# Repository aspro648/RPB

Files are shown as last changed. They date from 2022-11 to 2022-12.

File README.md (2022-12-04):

Rapid Prototyping Board
-------------------------------
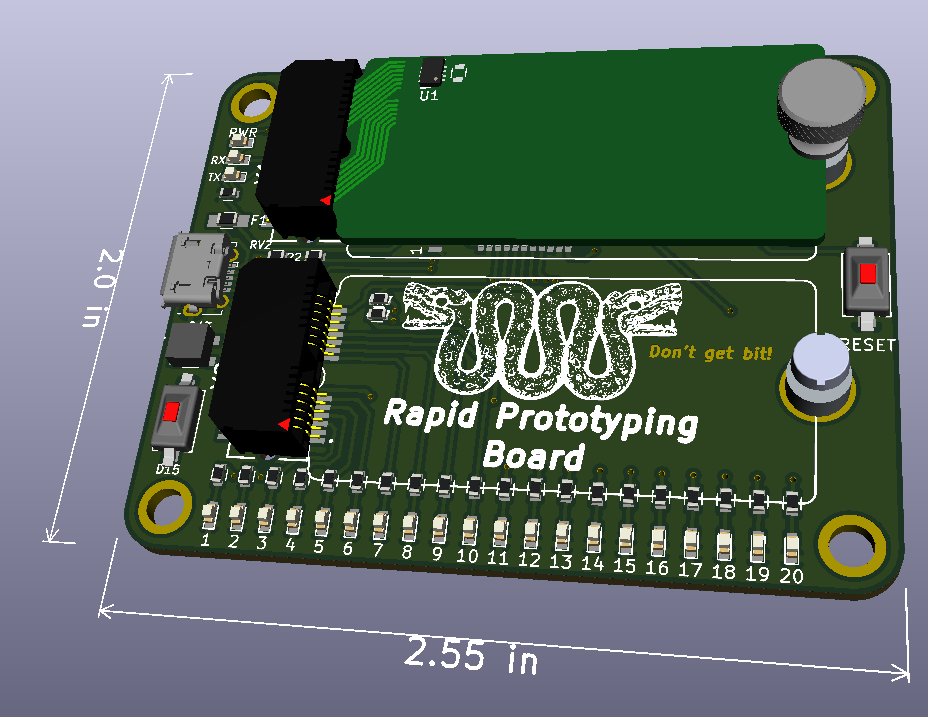
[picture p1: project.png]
 

What is it?
-----------

- Basically a 32U4 based Arduino with two card-edge slots instead of a shield layout.

Why?
----

- It started out as a 20-pin harness tester (Use Case 1), but morphed into a more generic prototyping system.
- Allows you to quickly prototype systems out on inexpensive small PCBs

Features:
---------

- USB programable Atmega 32U4.
- 20 i/o lines on card 1 position.
- Power, i2c, SPI on both card positions.
- Ability to check what card is plugged in each bay.

License
----------------
[Attribution-ShareAlike 3.0 United States (CC BY-SA 3.0 US)](https://creativecommons.org/licenses/by-sa/3.0/us/)

You are free to:

- Share — copy and redistribute the material in any medium or format
- Adapt — remix, transform, and build upon the material

Under the following terms:

- Attribution — You must give appropriate credit, provide a link to the license, and indicate if changes were made. You may do so in any reasonable manner, but not in any way that suggests the licensor endorses you or your use.
- ShareAlike — If you remix, transform, or build upon the material, you must distribute your contributions under the same license as the original.

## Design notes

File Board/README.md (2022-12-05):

Rapid Prototyping Board
-----------------------
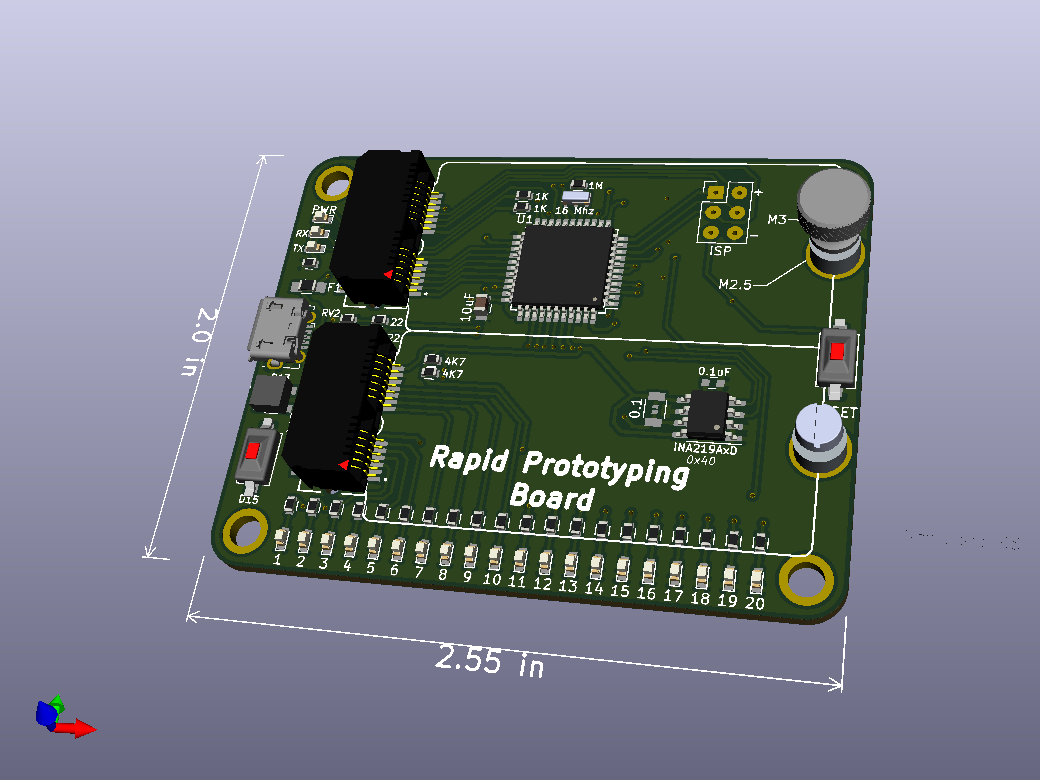
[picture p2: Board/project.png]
 

Bill Of Materials
----------------
  
- 1 ea., Perfect Purple PCB from OSH Park, https://oshpark.com/shared_projects/RGBCuiso
- 1 ea., U1 ATMEGA32U4-AU, IC MCU 8BIT 32KB FLASH 44TQFP, https://www.digikey.com/short/jb25pc
- 1 ea., U2 IC CURRENT MONITOR 1% 8SOIC, TI INA219AIDR, https://www.digikey.com/short/z32drn7n
- 1 ea., Y1 CER RES 16.0000MHZ 15PF SMD, Murata CSTNE16M0V530000R0, https://www.digikey.com/short/8nzcmjh3
- 2 ea., C1 CAP CER 10UF 10V X5R 0805, Kemet C0805C106K8PAC7800, https://www.digikey.com/short/32v75tfv
- 1 ea., C2 CAP CER 0.1uF 0603, https://www.digikey.com/short/h3jddqhm 
- 23 ea., D1-D23 SMD LED GREEN 0603, Lite-On LTST-C191KGKT, https://www.digikey.com/short/ptwhtwz2
- 1 ea., F1	PTC RESET FUSE 6V 500MA 0805 Eaton PTS08056V050, https://www.digikey.com/short/4182mdqq
- 2 ea., RV1, RV2 VARISTOR 10.8V 30A 0603, KYOCERA VCUG060050L1DP, https://www.digikey.com/short/0479hw0m
- 23 ea., R1-R23 Resistor 1K OHM SMD 0603, Stackpole RNCP0603FTD1K00, https://www.digikey.com/short/704h9hfn
- 2 ea., R24, R25 Resistor 22 OHM SMD 0603, Yageo RC0603JR-0722RL, https://www.digikey.com/short/93jrm3t2
- 1 ea., R26 Resistor 1M OHM SMD 0603 Yageo RC0603JR-071ML, https://www.digikey.com/short/z0jnrwbq
- 2 ea., R27, R28 Resistor 4K7 OHM SMD 0603, https://www.digikey.com/short/t89ptvpw
- 1 ea., R29 RES 0.1 OHM 1% 1W 1206, VSRP1206S1-R100F, https://www.digikey.com/short/dzw3vt1h
- 2 ea., SW1 SWITCH TACTILE SPST-NO 0.05A 12V, Wurth 434121025816, https://www.digikey.com/short/qbm0p0c9
- 1 ea., J1 CONN RCPT MICRO USB R/A SMD, Molex 1050170001, https://www.digikey.com/short/jb2205
- 2 ea., X1, X2 CONN EDGE DUAL FMALE 20POS, Samtek MEC8-113-02-L-D-RA1, https://www.digikey.com/short/50wdhmp0
- 2 ea., ROUND STANDOFF M2.5 STEEL 2.7MM, Wurth 9774027151R, https://www.digikey.com/short/47zwt3m4
- 1 ea., LED1 3535 RGB LED,  IN-PI33TBTPRPGPB https://www.digikey.com/short/qf2t8bqj
- 4 ea., BUMPER CYLINDRICAL 0.25" DIA CLR, https://www.digikey.com/short/23cbvbh5
- 2 ea., M2.5 thumbscrew https://www.mcmaster.com/99607A263/ or
		 https://www.amazon.com/CNBTR-M2-5x6mm-Knurled-Threaded-Fastener/dp/B07ZJFGGTD

Card:
- 1 ea., RPB Card 2.54mm Pitch, https://oshpark.com/shared_projects/RnMvuNFo
- 1 ea., RES 10K OHM 5% 1/10W 0603, https://www.digikey.com/short/h4w9vtd1
- 1 ea., IC EEPROM 32KBIT I2C, Microchip 24LC32AT-I/MC, https://www.digikey.com/short/r3f225vm
- 1 ea., I2C Display Module 0.91 Inch I2C, https://www.amazon.com/Pieces-Display-Module-SSD1306-Screen/dp/B08N6N8L5Q

Stencil & Jig:
- https://www.oshstencils.com/#invoice/5585b4301f5fdfe7690882e8abfac3aeba5187

License
----------------
[Attribution-ShareAlike 3.0 United States (CC BY-SA 3.0 US)](https://creativecommons.org/licenses/by-sa/3.0/us/)

You are free to:

- Share — copy and redistribute the material in any medium or format
- Adapt — remix, transform, and build upon the material

Under the following terms:

- Attribution — You must give appropriate credit, provide a link to the license, and indicate if changes were made. You may do so in any reasonable manner, but not in any way that suggests the licensor endorses you or your use.
- ShareAlike — If you remix, transform, or build upon the material, you must distribute your contributions under the same license as the original.

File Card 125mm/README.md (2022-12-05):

Rapid Prototyping Card - 1.25mm Pitch
-------------------------------------

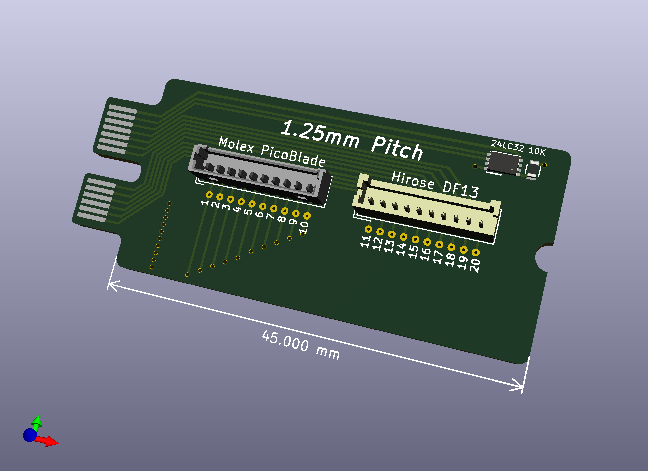
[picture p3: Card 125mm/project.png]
 

Bill Of Materials
----------------
  
- PCB from KiCad project.kicad_pcb file  
- 1 ea., RES 10K OHM 5% 1/10W 0603, https://www.digikey.com/short/h4w9vtd1
- 1 ea., IC EEPROM 32KBIT I2C, Microchip 24LC32AT-I/MC, https://www.digikey.com/short/r3f225vm
- 1 ea., CONN HEADER VERT 10POS 1.25MM, Molex 0530471010, https://www.digikey.com/short/jfwfhm5n
- 1 ea., CONN HEADER VERT 10POS 1.25MM, Hirose DF13-10P-1.25DSA, https://www.digikey.com/short/f5pm7mt2

License
----------------
[Attribution-ShareAlike 3.0 United States (CC BY-SA 3.0 US)](https://creativecommons.org/licenses/by-sa/3.0/us/)

You are free to:

- Share — copy and redistribute the material in any medium or format
- Adapt — remix, transform, and build upon the material

Under the following terms:

- Attribution — You must give appropriate credit, provide a link to the license, and indicate if changes were made. You may do so in any reasonable manner, but not in any way that suggests the licensor endorses you or your use.
- ShareAlike — If you remix, transform, or build upon the material, you must distribute your contributions under the same license as the original.

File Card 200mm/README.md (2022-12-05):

Rapid Prototyping Card - 2.00mm Pitch
-------------------------------------

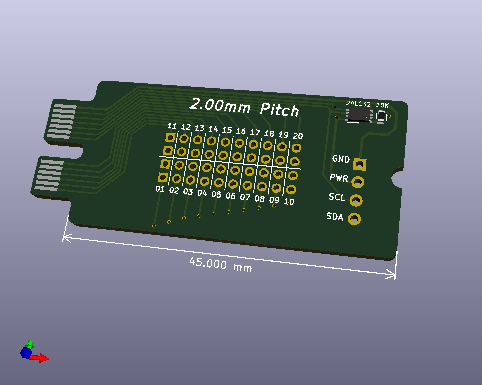
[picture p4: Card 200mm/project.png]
 

Bill Of Materials
----------------
  
- PCB from KiCad project.kicad_pcb file  
- 1 ea., RES 10K OHM 5% 1/10W 0603, https://www.digikey.com/short/h4w9vtd1
- 1 ea., IC EEPROM 32KBIT I2C, Microchip 24LC32AT-I/MC, https://www.digikey.com/short/r3f225vm

License
----------------
[Attribution-ShareAlike 3.0 United States (CC BY-SA 3.0 US)](https://creativecommons.org/licenses/by-sa/3.0/us/)

You are free to:

- Share — copy and redistribute the material in any medium or format
- Adapt — remix, transform, and build upon the material

Under the following terms:

- Attribution — You must give appropriate credit, provide a link to the license, and indicate if changes were made. You may do so in any reasonable manner, but not in any way that suggests the licensor endorses you or your use.
- ShareAlike — If you remix, transform, or build upon the material, you must distribute your contributions under the same license as the original.

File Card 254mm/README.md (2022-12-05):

Rapid Prototyping Card - 2.54mm Pitch
-------------------------------------

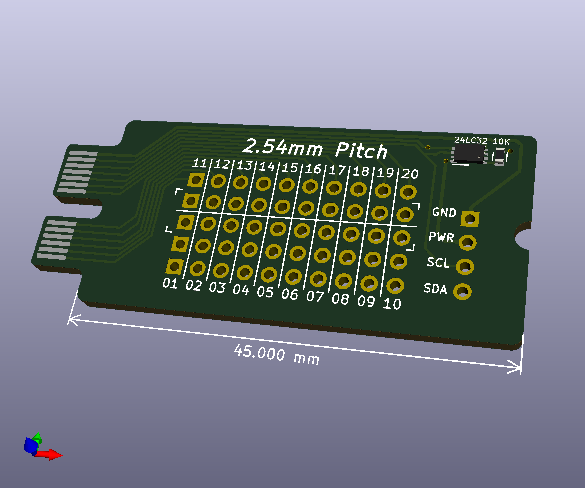
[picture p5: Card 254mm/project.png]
 

Bill Of Materials
----------------
  
- PCB from KiCad project.kicad_pcb file  
- 1 ea., RES 10K OHM 5% 1/10W 0603, https://www.digikey.com/short/h4w9vtd1
- 1 ea., IC EEPROM 32KBIT I2C, Microchip 24LC32AT-I/MC, https://www.digikey.com/short/r3f225vm

License
----------------
[Attribution-ShareAlike 3.0 United States (CC BY-SA 3.0 US)](https://creativecommons.org/licenses/by-sa/3.0/us/)

You are free to:

- Share — copy and redistribute the material in any medium or format
- Adapt — remix, transform, and build upon the material

Under the following terms:

- Attribution — You must give appropriate credit, provide a link to the license, and indicate if changes were made. You may do so in any reasonable manner, but not in any way that suggests the licensor endorses you or your use.
- ShareAlike — If you remix, transform, or build upon the material, you must distribute your contributions under the same license as the original.

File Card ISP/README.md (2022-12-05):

Rapid Prototyping Card - ArduinoISP
---------------------------------------
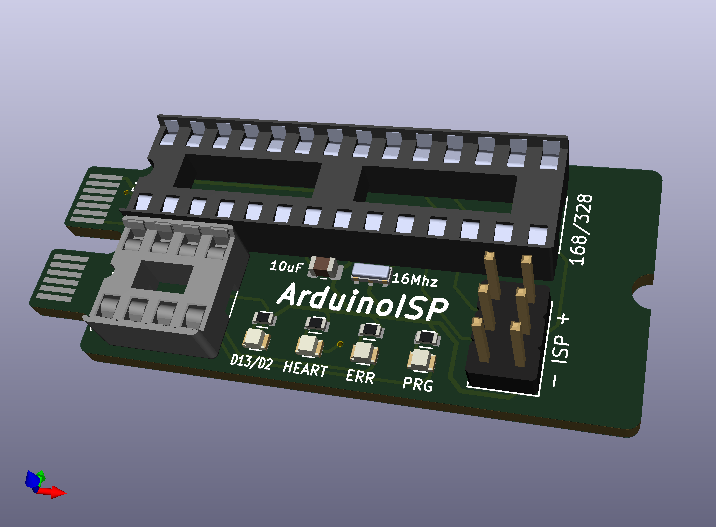
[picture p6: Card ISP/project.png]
 

What is it?
-----------

- Use RPB as an ISP programmer. 
- Sockets for Atmega8/168/328 & Attiny25/24/85.
- ISP jumper for on-board programming.
- D13 (Atmega) and D2 (Attiny) LED for troubleshooting.
- Fused to prevent reversed Attiny meltdown!

Bill Of Materials
----------------
  
- 1 ea., Perfect Purple PCB from OSH Park, https://oshpark.com/shared_projects/yUt0KZ6C
- 2 ea., C1 CAP CER 10UF 10V X5R 0805, Kemet C0805C106K8PAC7800, https://www.digikey.com/short/32v75tfv
- 2 ea., SMD LED GREEN 0603, Lite-On LTST-C191KGKT, https://www.digikey.com/short/ptwhtwz2
- 1 ea., SMD LED RED 0603, Lite-On LTST-C191KRKT, https://www.digikey.com/short/1p9dvv1t
- 1 ea., SMD LED YELLOW 0603, Lite-On LTST-C191KSKT, https://www.digikey.com/short/d20z9t1z
- 1 ea., PTC RESET FUSE 20V 54MA 0805, Murata PRG21AR420MB1RA, https://www.digikey.com/short/2nmhrbvf
- 4 ea., Resistor 1K OHM SMD 0603, Stackpole RNCP0603FTD1K00, https://www.digikey.com/short/704h9hfn
- 1 ea., CONN IC DIP SOCKET 28POS TIN, On Shore ED281DT, https://www.digikey.com/short/d8nq4rd3
- 1 ea., CONN IC DIP SOCKET 8POS, On Shore ED08DT, https://www.digikey.com/short/3tnrjzh5
- 1 ea., 6-PIN SOCKET/SOCKET IDC CABLE, Adafruit 371, https://www.digikey.com/short/b992qfbd
- 1 ea., CONN HEADER VERT 6POS 2.54MM, Amphenol 77313-118-06LF, https://www.digikey.com/short/r2d1pw4f

License
----------------
[Attribution-ShareAlike 3.0 United States (CC BY-SA 3.0 US)](https://creativecommons.org/licenses/by-sa/3.0/us/)

You are free to:

- Share — copy and redistribute the material in any medium or format
- Adapt — remix, transform, and build upon the material

Under the following terms:

- Attribution — You must give appropriate credit, provide a link to the license, and indicate if changes were made. You may do so in any reasonable manner, but not in any way that suggests the licensor endorses you or your use.
- ShareAlike — If you remix, transform, or build upon the material, you must distribute your contributions under the same license as the original.

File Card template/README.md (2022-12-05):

Rapid Prototyping Card - Template
---------------------------------
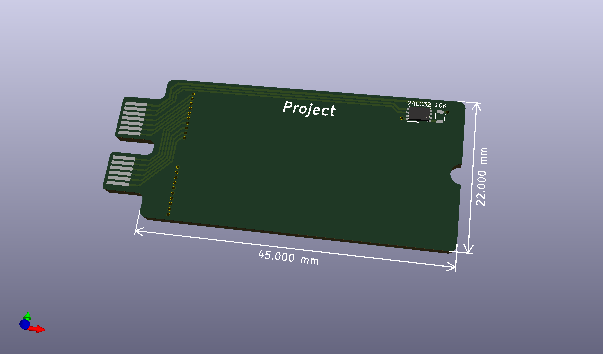
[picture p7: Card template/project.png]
 

Bill Of Materials
----------------

- PCB from KiCad project.kicad_pcb file  
- 1 ea., RES 10K OHM 5% 1/10W 0603, https://www.digikey.com/short/h4w9vtd1
- 1 ea., IC EEPROM 32KBIT I2C, Microchip 24LC32AT-I/MC, https://www.digikey.com/short/r3f225vm

License
----------------
[Attribution-ShareAlike 3.0 United States (CC BY-SA 3.0 US)](https://creativecommons.org/licenses/by-sa/3.0/us/)

You are free to:

- Share — copy and redistribute the material in any medium or format
- Adapt — remix, transform, and build upon the material

Under the following terms:

- Attribution — You must give appropriate credit, provide a link to the license, and indicate if changes were made. You may do so in any reasonable manner, but not in any way that suggests the licensor endorses you or your use.
- ShareAlike — If you remix, transform, or build upon the material, you must distribute your contributions under the same license as the original.

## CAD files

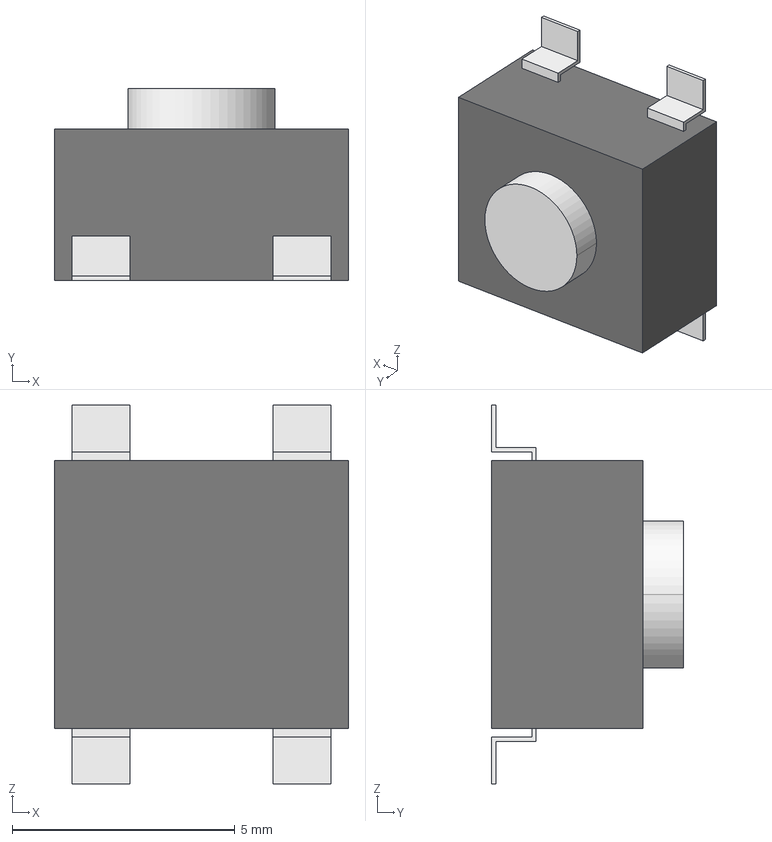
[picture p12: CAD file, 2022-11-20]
Board/3D/Button_b3s-1002p.stp
6.60 x 4.30 x 8.50 mm

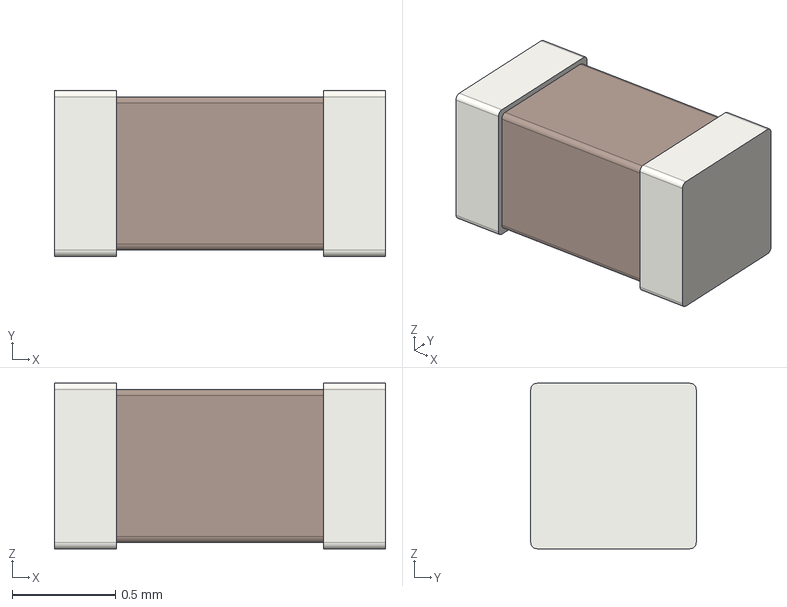
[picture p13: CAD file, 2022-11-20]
Board/3D/C_0603_1608Metric.step
1.60 x 0.8 x 0.8 mm

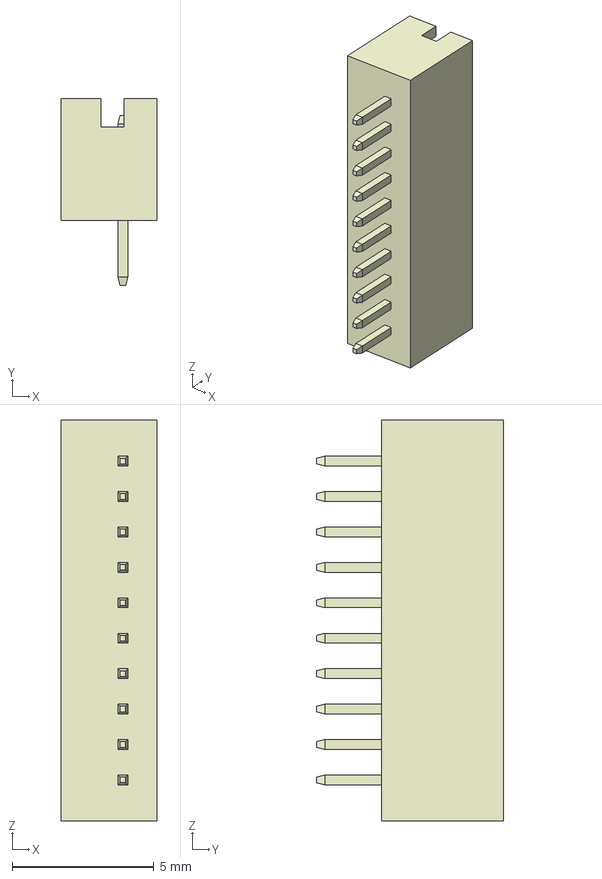
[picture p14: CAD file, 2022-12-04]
Card 125mm/3D/DF13-10P-1.25DSA.stp
3.40 x 6.60 x 14.1 mm

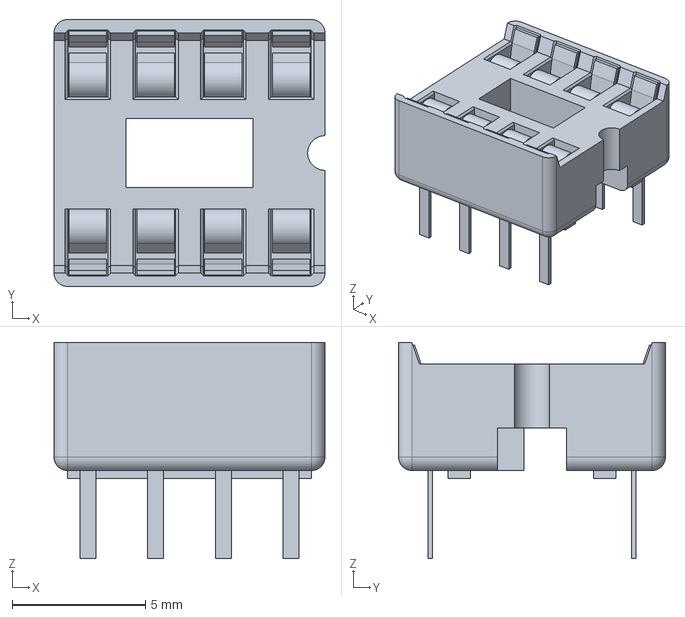
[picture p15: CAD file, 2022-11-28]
Card ISP/3D/c-1-2199298-2-a-3d.stp
10.2 x 10.0 x 8.10 mm

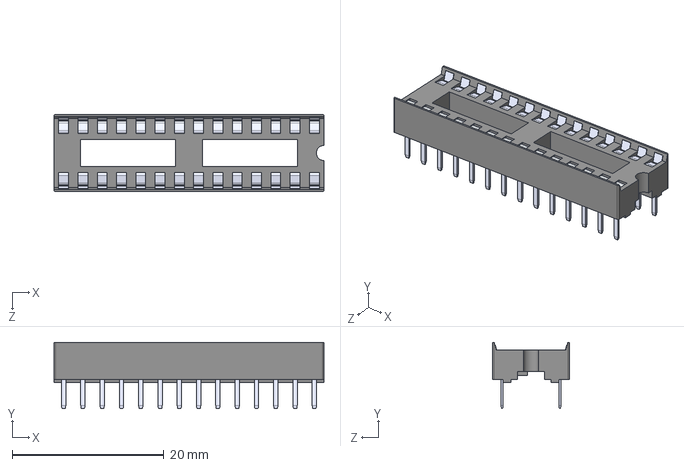
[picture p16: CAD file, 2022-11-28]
Card ISP/3D/ED281DT--3DModel-STEP-56544.STEP
35.6 x 8.70 x 10.2 mm

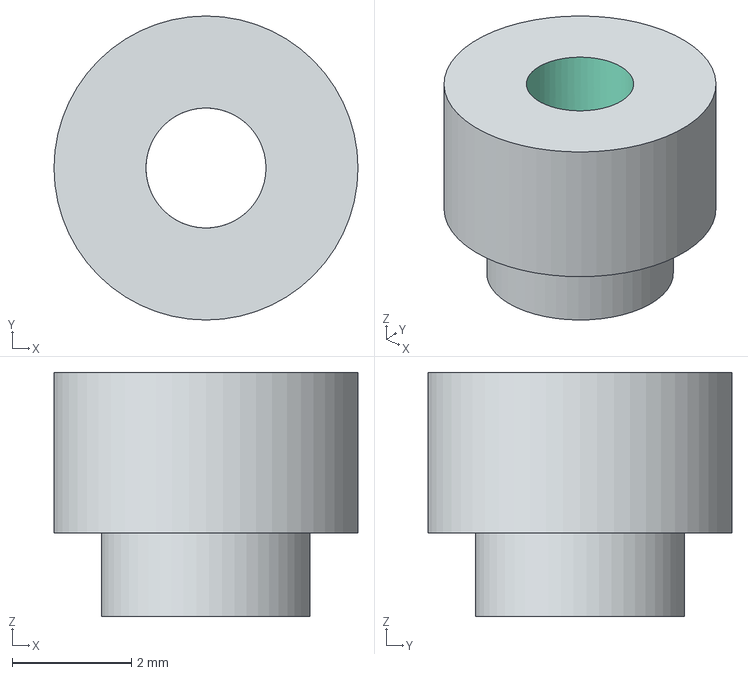
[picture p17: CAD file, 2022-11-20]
Board/3D/standoff9774027151R (rev1).stp
5.10 x 5.10 x 4.10 mm

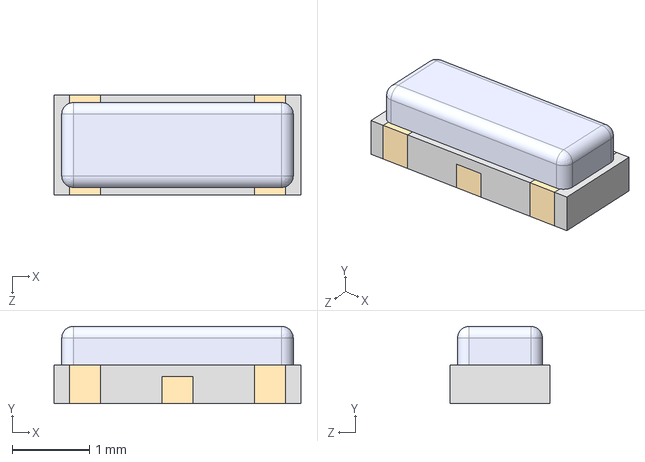
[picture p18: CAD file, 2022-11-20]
Card ISP/3D/resontator_CSTNE16M0V530000R0.STEP
3.20 x 1.00 x 1.30 mm

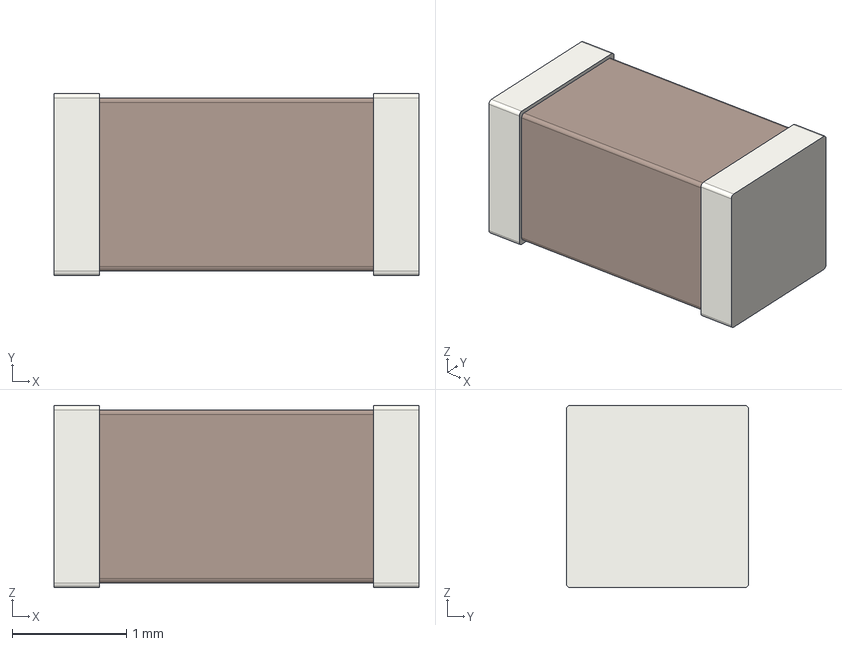
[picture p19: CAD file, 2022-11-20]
Board/3D/C_1206_3216Metric.step
3.20 x 1.60 x 1.60 mm

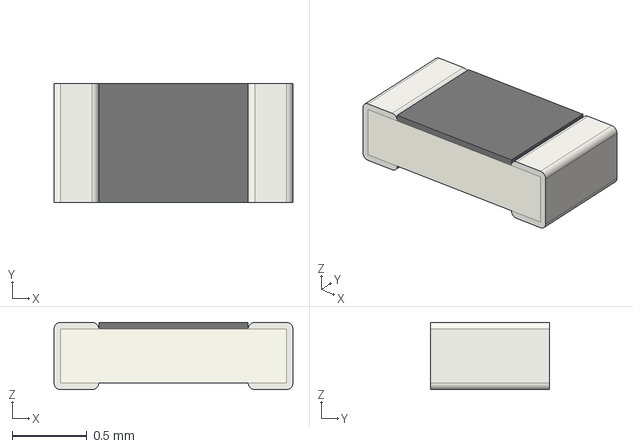
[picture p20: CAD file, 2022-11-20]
Board/3D/R_0603_1608Metric.step
1.60 x 0.8 x 0.45 mm

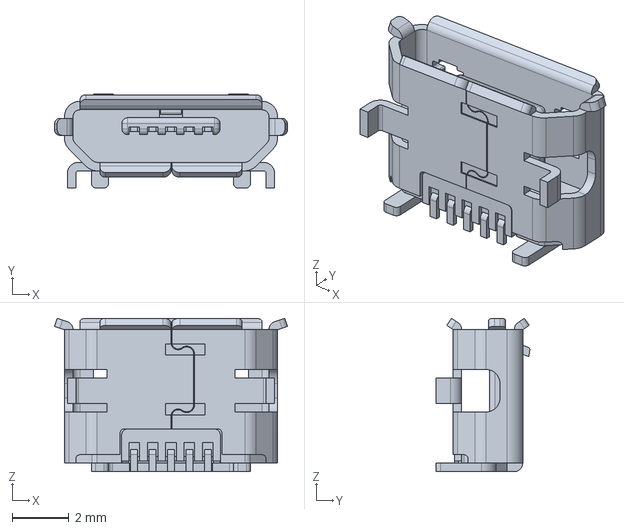
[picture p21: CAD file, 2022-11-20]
Board/3D/USB_micro_105017-0001.stp
8.20 x 3.30 x 5.40 mm

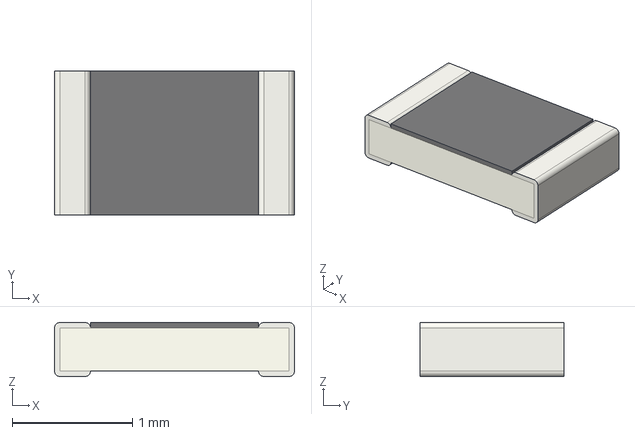
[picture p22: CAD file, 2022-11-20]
Board/3D/R_0805_2012Metric.step
2.00 x 1.20 x 0.45 mm

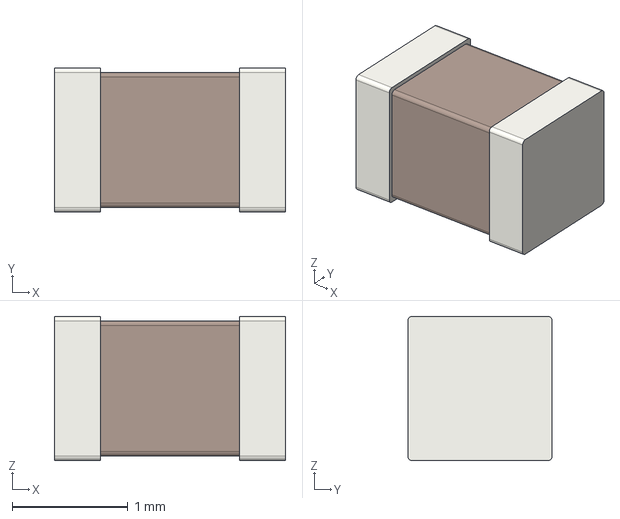
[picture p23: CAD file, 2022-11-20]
Board/3D/C_0805_2012Metric.step
2.00 x 1.25 x 1.25 mm

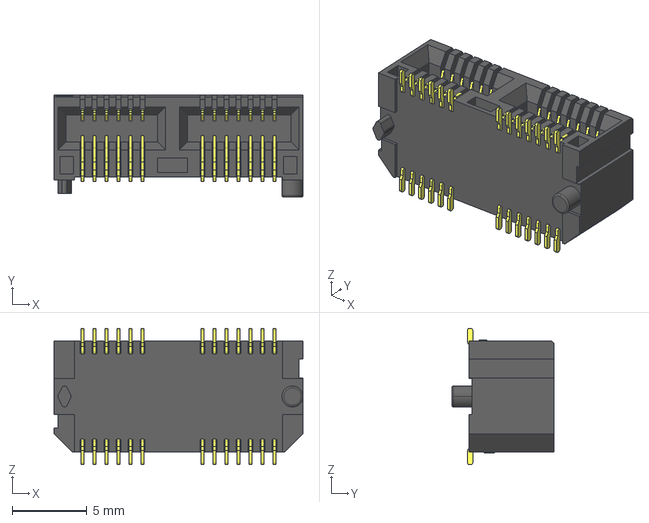
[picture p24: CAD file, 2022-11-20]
Board/3D/mec8-113-02-l-d-ra1.stp
16.6 x 6.83 x 9.10 mm

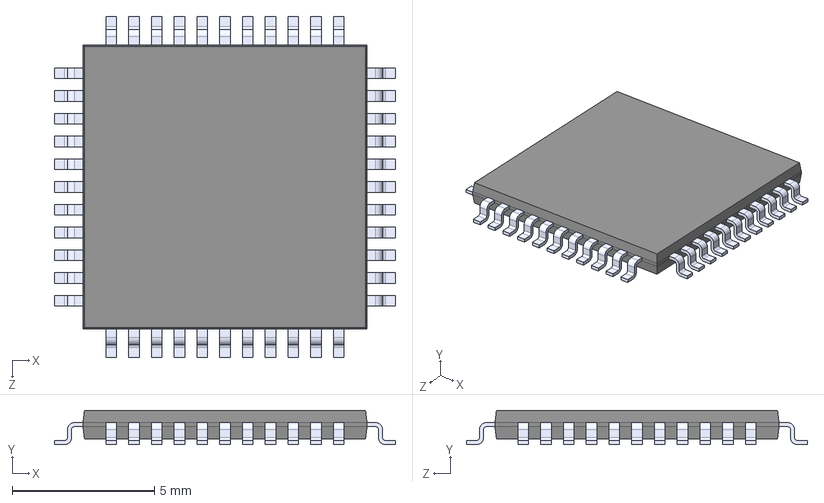
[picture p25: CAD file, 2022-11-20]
Board/3D/ATMEGA32U4-AUR--3DModel-STEP-56544.STEP
12.0 x 1.20 x 12.0 mm

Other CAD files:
Board/3D/1655.step
Card 125mm/3D/530471010.stp
Card ISP/3D/61200621621_Download_STP_61200621621_rev1.stp
Board/3D/M2_5X6MM.step

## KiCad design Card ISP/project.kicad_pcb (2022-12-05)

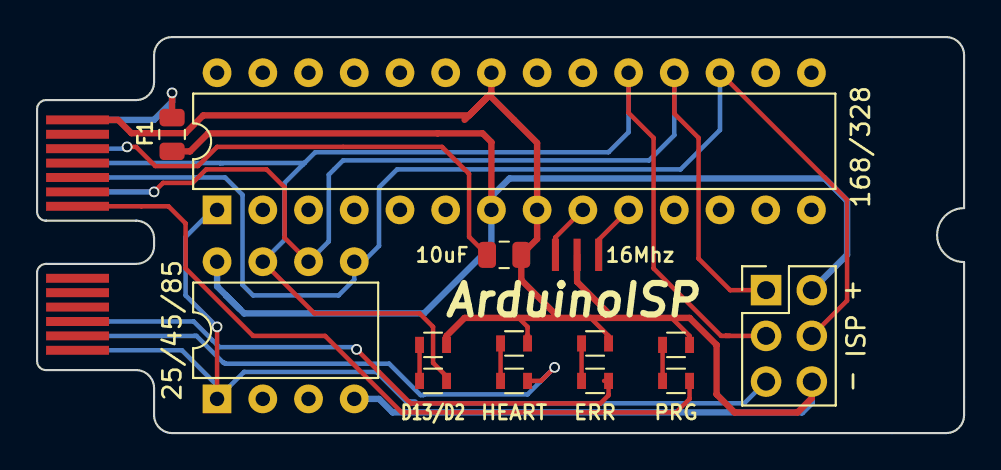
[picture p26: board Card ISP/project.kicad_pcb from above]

Board: 2 copper layers, 51.5 x 22.0 mm, 15 parts (0 on the bottom side), 17 nets.

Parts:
C1: 10uF; C_0805_2012Metric
D1: HEART; R_0603
D2: ERR; R_0603
D3: PRG; R_0603
D4: D13/D2; R_0603
F1: 54mA; Fuse_0805_2012Metric
J1: ISP; PinHeader_2x03_P2.54mm_Vertical
R1, R2, R3, R4: 1K; R_0603
U1: 25/45/85; DIP-8_W7.62mm
U2: 168/328; DIP-28_W7.62mm
X0: Card Edge; MEC8-113-CARD_2
Y1: 16Mhz; Resonator_SMD_CTSC_1.3mmx3.2mm

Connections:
+5V: F1.2, J1.2, U1.8, U2.7
/LED_ERR: D2.2, X0.3
/LED_HB: D1.2, X0.2
/LED_PMODE: D3.2, X0.20
/MISO: J1.1, U1.6, U2.18, X0.8
/MOSI: J1.4, U1.5, U2.17, X0.9
/RESET: C1.1, X0.11
/RST: J1.5, U1.1, U2.1, X0.1
/SCK: D4.2, J1.3, U1.7, U2.19, X0.10
GND: C1.2, J1.6, R1.1, R2.1, R3.1, R4.1, U1.4, U2.8, U2.22, X0.26, Y1.2
unnamed: D1.1, R2.2
unnamed: D2.1, R3.2
unnamed: D3.1, R4.2
unnamed: D4.1, R1.2
unnamed: F1.1, X0.13
unnamed: U2.9, Y1.3
unnamed: U2.10, Y1.1

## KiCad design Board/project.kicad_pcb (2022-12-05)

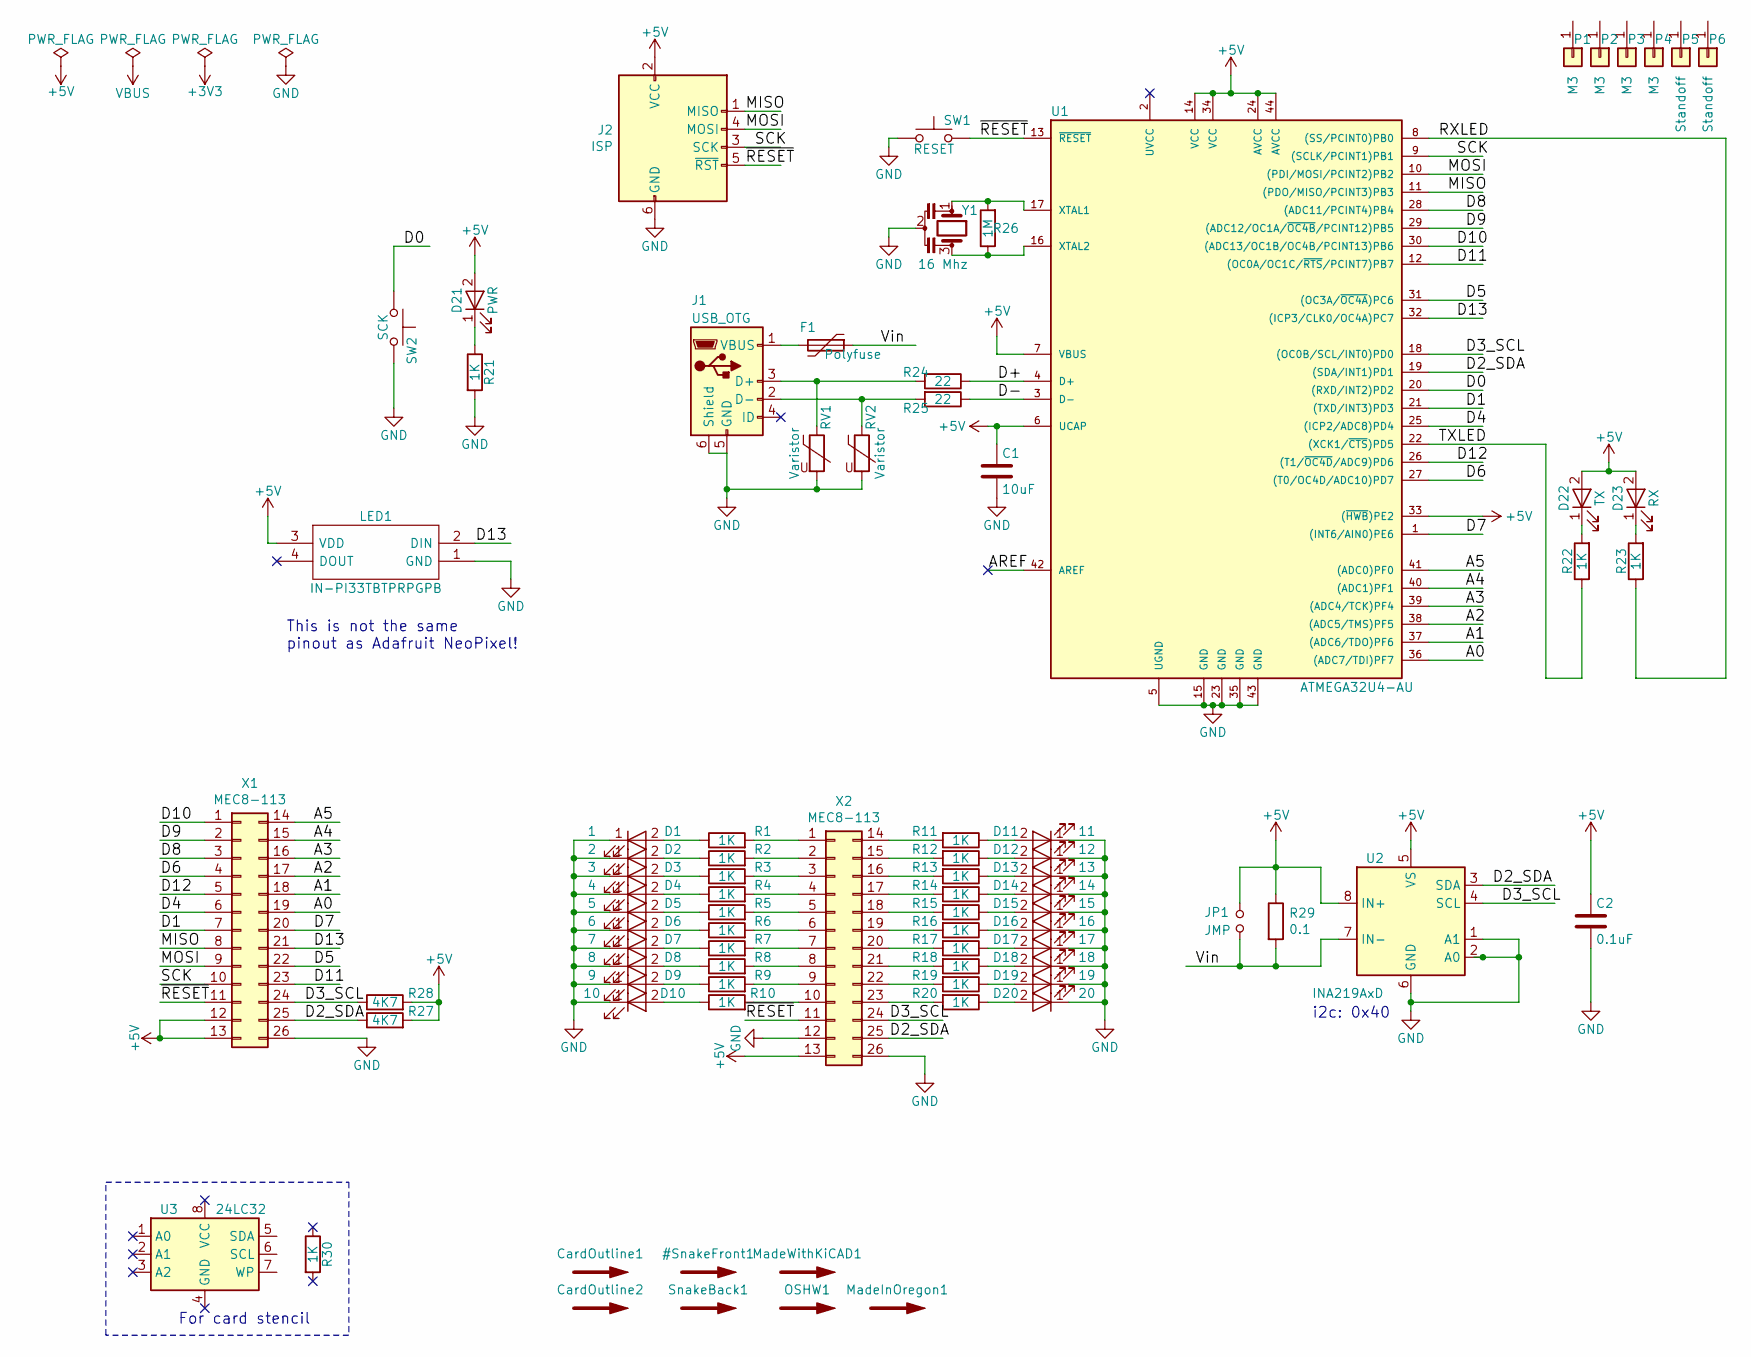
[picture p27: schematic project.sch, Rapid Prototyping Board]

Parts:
C1: 10uF; C_0805
C2: 0.1uF; C_0603
CardOutline1, CardOutline2: SYM_Arrow_Large; MEC8-113-CARD_2outline
D1: 1; LED_0603
D2: 2; LED_0603
D3: 3; LED_0603
D4: 4; LED_0603
D5: 5; LED_0603
D6: 6; LED_0603
D7: 7; LED_0603
D8: 8; LED_0603
D9: 9; LED_0603
D10: 10; LED_0603
D11: 11; LED_0603
D12: 12; LED_0603
D13: 13; LED_0603
D14: 14; LED_0603
D15: 15; LED_0603
D16: 16; LED_0603
D17: 17; LED_0603
D18: 18; LED_0603
D19: 19; LED_0603
D20: 20; LED_0603
D21: PWR; LED_0603
D22: TX; LED_0603
D23: RX; LED_0603
F1: Polyfuse; R_0805_HandSoldering
J1: USB_OTG; USB_Micro-B_Molex-105017-0001
J2: ISP; Pin_Header_Straight_2x03_Pitch2.54mm
JP1: JMP; Jumper
LED1: IN-PI33TBTPRPGPB; INPI33TBTPRPGPB; Mouser Part Number 743-IN-PI33TBTPRPGPB
MadeInOregon1: SYM_Arrow_Large; MadeInOregonRev25
MadeWithKiCAD1: SYM_Arrow_Large; KiCad-Logo2_8mm_SilkScreen
OSHW1: SYM_Arrow_Large; OSHW-Logo_11.4x12mm_SilkScreen
P1, P2, P3, P4: M3; M3mount
P5, P6: Standoff; M25standoff
R1, R2, R3, R4, R5, R6, R7, R8, R9, R10, R11, R12, R13, R14, R15, R16, R17, R18, R19, R20, R21, R22, R23, R30: 1K; R_0603
R24, R25: 22; R_0603
R26: 1M; R_0603
R27, R28: 4K7; R_0603
R29: 0.1; R_1206
RV1, RV2: Varistor; R_0603
SW1: RESET; SW_TS10-63-26-BE-250-SMT-TR
SW2: SCK; SW_TS10-63-26-BE-250-SMT-TR
SnakeBack1: SYM_Arrow_Large; Snake
U1: ATMEGA32U4-AU; TQFP-44_10x10mm_Pitch0.8mm
U2: INA219AxD; SOIC-8_3.9x4.9mm_P1.27mm
U3: 24LC32; DFN-8-1EP_3x2mm
X1, X2: MEC8-113; SAMTEC_MEC8-113-TOP-BOTTOM
Y1: 16 Mhz; Resonator_SMD_CTSC_1.3mmx3.2mm

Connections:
+5V: C1.1, C2.1, D21.2 (A), D22.2 (A), D23.2 (A), J2.2 (VCC), JP1.1, LED1.3 (VDD), R27.2, R28.2, R29.1, U1.6 (UCAP), U1.7 (VBUS), U1.14 (VCC), U1.24 (AVCC), U1.33 ((~HWB~)PE2), U1.34 (VCC), U1.44 (AVCC), U2.5 (VS), U2.8 (IN+), X1.12, X1.13, X2.13
/A0: U1.36 ((ADC7/TDI)PF7), X1.19
/A1: U1.37 ((ADC6/TDO)PF6), X1.18
/A2: U1.38 ((ADC5/TMS)PF5), X1.17
/A3: U1.39 ((ADC4/TCK)PF4), X1.16
/A4: U1.40 ((ADC1)PF1), X1.15
/A5: U1.41 ((ADC0)PF0), X1.14
/D0: SW2.1, U1.20 ((RXD/INT2)PD2)
/D1: U1.21 ((TXD/INT3)PD3), X1.7
/D2_SDA: R27.1, U1.19 ((SDA/INT1)PD1), U2.3 (SDA), X1.25, X2.25
/D3_SCL: R28.1, U1.18 ((OC0B/SCL/INT0)PD0), U2.4 (SCL), X1.24, X2.24
/D4: U1.25 ((ICP2/ADC8)PD4), X1.6
/D5: U1.31 ((OC3A/~OC4A~)PC6), X1.22
/D6: U1.27 ((T0/OC4D/ADC10)PD7), X1.4
/D7: U1.1 ((INT6/AIN0)PE6), X1.20
/D8: U1.28 ((ADC11/PCINT4)PB4), X1.3
/D9: U1.29 ((ADC12/OC1A/~OC4B~/PCINT12)PB5), X1.2
/D10: U1.30 ((ADC13/OC1B/OC4B/PCINT13)PB6), X1.1
/D11: U1.12 ((OC0A/OC1C/~RTS~/PCINT7)PB7), X1.23
/D12: U1.26 ((T1/~OC4D~/ADC9)PD6), X1.5
/D13: LED1.2 (DIN), U1.32 ((ICP3/CLK0/OC4A)PC7), X1.21
/D+: R24.1, U1.4 (D+)
/D-: R25.1, U1.3 (D-)
/MISO: J2.1 (MISO), U1.11 ((PDO/MISO/PCINT3)PB3), X1.8
/MOSI: J2.4 (MOSI), U1.10 ((PDI/MOSI/PCINT2)PB2), X1.9
/RXLED: R23.1, U1.8 ((SS/PCINT0)PB0)
/SCK: J2.3 (SCK), U1.9 ((SCLK/PCINT1)PB1), X1.10
/TXLED: R22.1, U1.22 ((XCK1/~CTS~)PD5)
/Vin: F1.1, JP1.2, R29.2, U2.7 (IN-)
/~RESET: J2.5 (~RST), SW1.2, U1.13 (~RESET~), X1.11, X2.11
GND: C1.2, C2.2, D1.1 (K), D2.1 (K), D3.1 (K), D4.1 (K), D5.1 (K), D6.1 (K), D7.1 (K), D8.1 (K), D9.1 (K), D10.1 (K), D11.1 (K), D12.1 (K), D13.1 (K), D14.1 (K), D15.1 (K), D16.1 (K), D17.1 (K), D18.1 (K), D19.1 (K), D20.1 (K), J1.5 (GND), J1.6 (Shield), J2.6 (GND), LED1.1 (GND), R21.2, RV1.2, RV2.2, SW1.1, SW2.2, U1.5 (UGND), U1.15 (GND), U1.23 (GND), U1.35 (GND), U1.43 (GND), U2.1 (A1), U2.2 (A0), U2.6 (GND), X1.26, X2.12, X2.26, Y1.2
unnamed: D1.2 (A), R1.1
unnamed: D2.2 (A), R2.1
unnamed: D3.2 (A), R3.1
unnamed: D4.2 (A), R4.1
unnamed: D5.2 (A), R5.1
unnamed: D6.2 (A), R6.1
unnamed: D7.2 (A), R7.1
unnamed: D8.2 (A), R8.1
unnamed: D9.2 (A), R9.1
unnamed: D10.2 (A), R10.1
unnamed: D11.2 (A), R11.1
unnamed: D12.2 (A), R12.1
unnamed: D13.2 (A), R13.1
unnamed: D14.2 (A), R14.1
unnamed: D15.2 (A), R15.1
unnamed: D16.2 (A), R16.1
unnamed: D17.2 (A), R17.1
unnamed: D18.2 (A), R18.1
unnamed: D19.2 (A), R19.1
unnamed: D20.2 (A), R20.1
unnamed: D21.1 (K), R21.1
unnamed: D22.1 (K), R22.2
unnamed: D23.1 (K), R23.2
unnamed: F1.2, J1.1 (VBUS)
unnamed: J1.2 (D-), R25.2, RV2.1
unnamed: J1.3 (D+), R24.2, RV1.1
unnamed: R1.2, X2.1
unnamed: R2.2, X2.2
unnamed: R3.2, X2.3
unnamed: R4.2, X2.4
unnamed: R5.2, X2.5
unnamed: R6.2, X2.6
unnamed: R7.2, X2.7
unnamed: R8.2, X2.8
unnamed: R9.2, X2.9
unnamed: R10.2, X2.10
unnamed: R11.2, X2.14
unnamed: R12.2, X2.15
unnamed: R13.2, X2.16
unnamed: R14.2, X2.17
unnamed: R15.2, X2.18
unnamed: R16.2, X2.19
unnamed: R17.2, X2.20
unnamed: R18.2, X2.21
unnamed: R19.2, X2.22
unnamed: R20.2, X2.23
unnamed: R26.1, U1.16 (XTAL2), Y1.3
unnamed: R26.2, U1.17 (XTAL1), Y1.1

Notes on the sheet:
This is not the same pinout as Adafruit NeoPixel!
i2c: 0x40
For card stencil

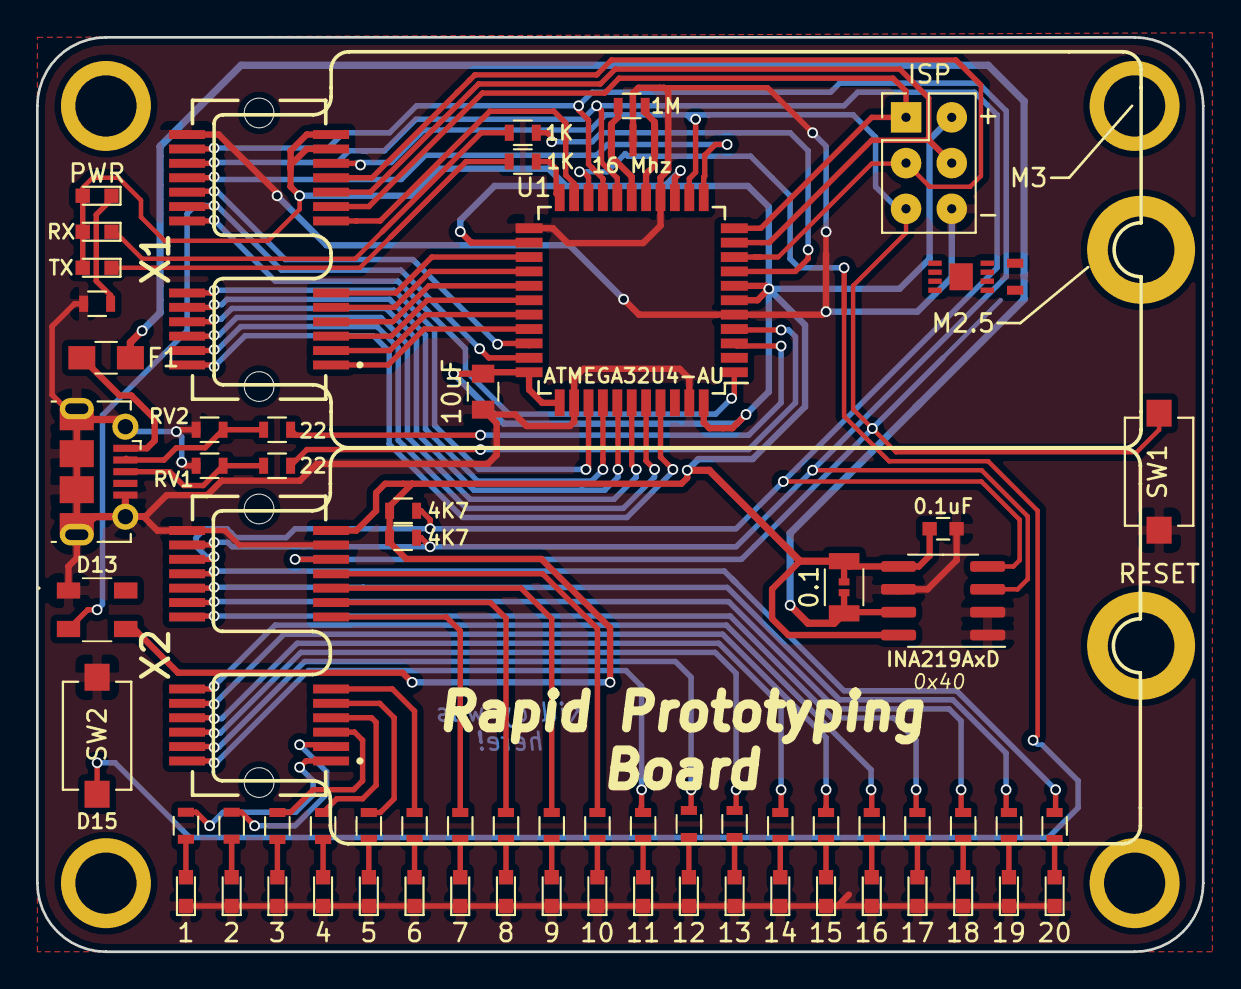
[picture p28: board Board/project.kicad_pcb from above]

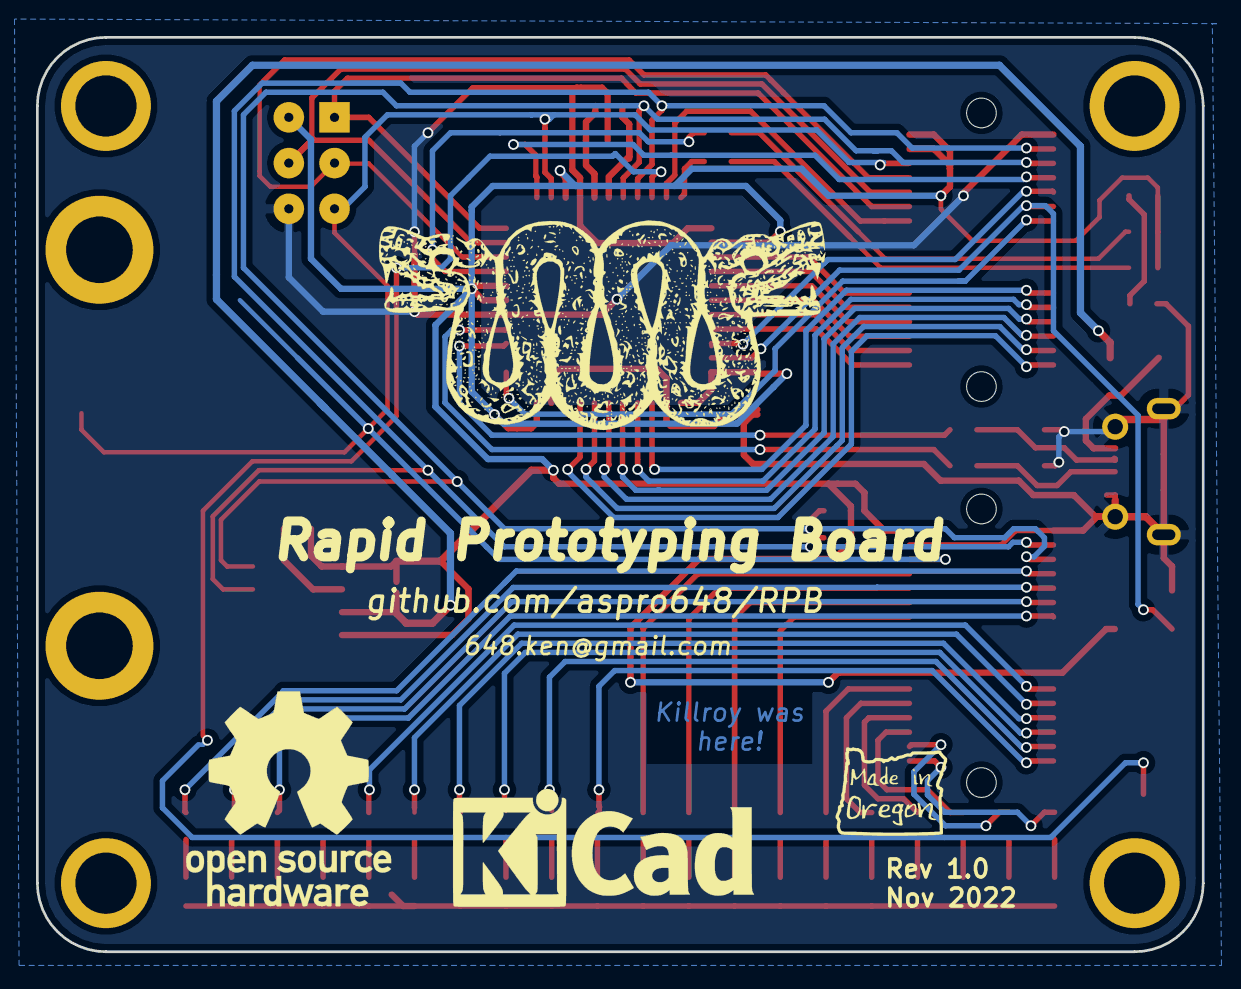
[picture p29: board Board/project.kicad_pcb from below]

Board: 2 copper layers, 64.8 x 50.8 mm, 82 parts (3 on the bottom side), 79 nets.

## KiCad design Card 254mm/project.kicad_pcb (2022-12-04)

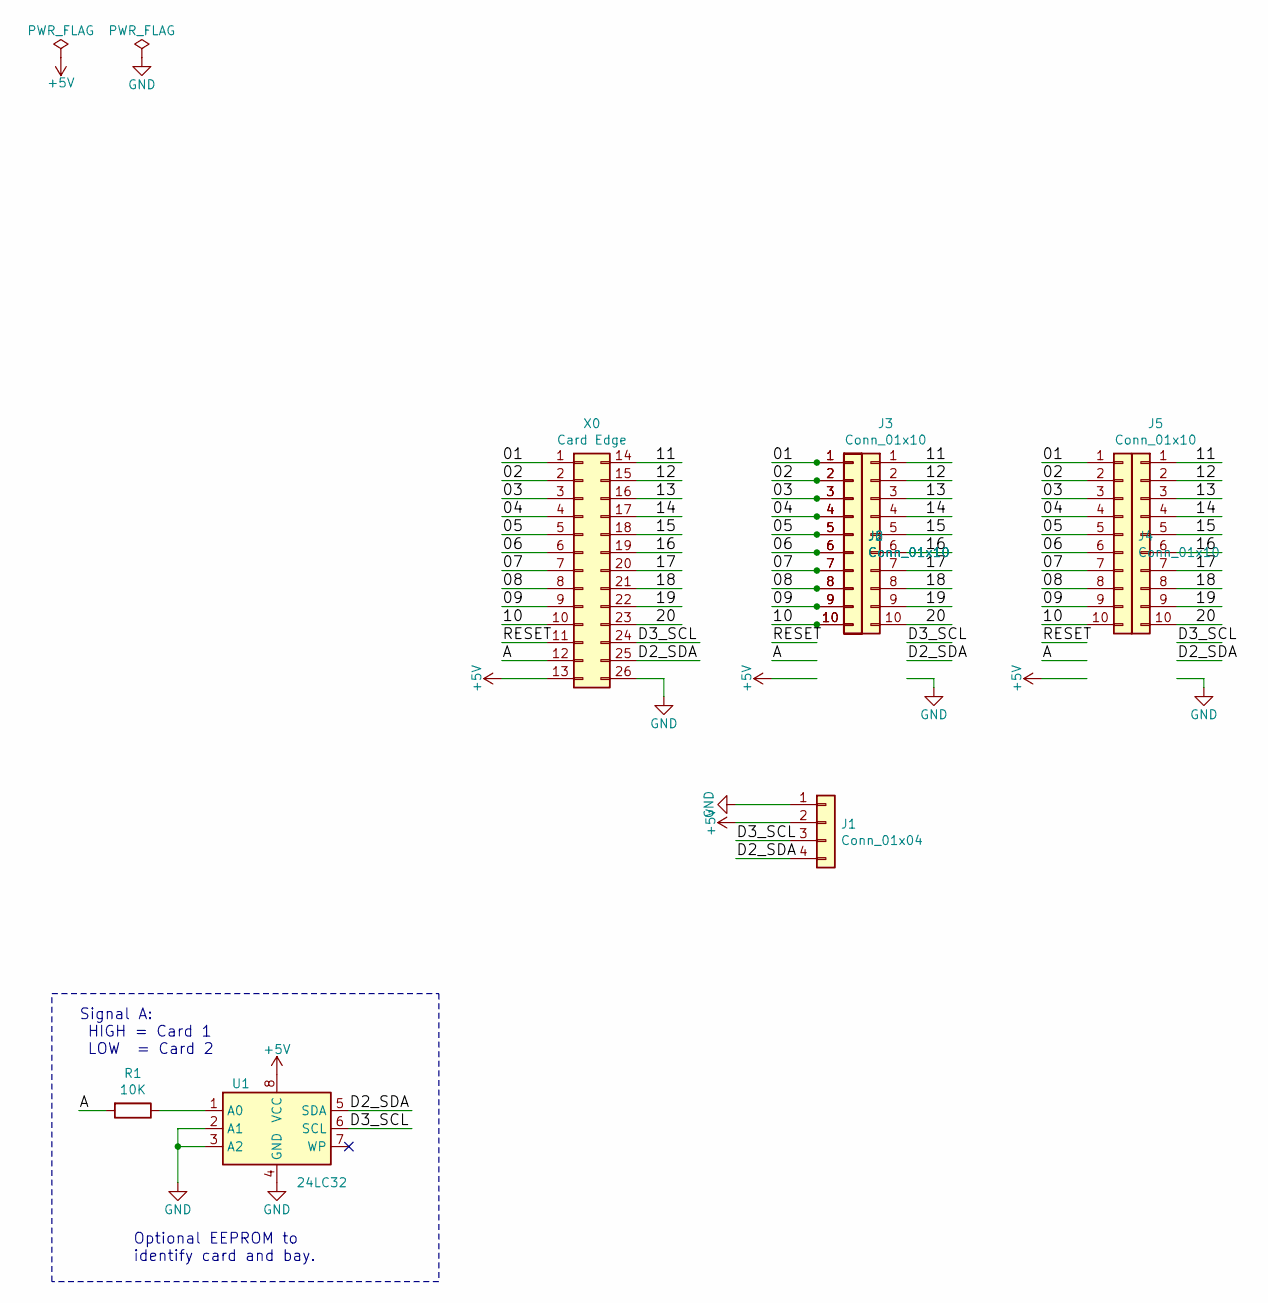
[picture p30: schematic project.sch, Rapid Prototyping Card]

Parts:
J1: Conn_01x04; PinHeader_1x04_P2.54mm_Vertical
J2, J3, J4, J5, J6: Conn_01x10; PinHeader_1x10_P2.54mm_Vertical
R1: 10K; R_0603
U1: 24LC32; DFN-8-1EP_3x2mm
X0: Card Edge; MEC8-113-CARD_2

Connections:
+5V: J1.2, U1.8 (VCC), X0.13
/01: J2.1, J4.1, J6.1, X0.1
/02: J2.2, J4.2, J6.2, X0.2
/03: J2.3, J4.3, J6.3, X0.3
/04: J2.4, J4.4, J6.4, X0.4
/05: J2.5, J4.5, J6.5, X0.5
/06: J2.6, J4.6, J6.6, X0.6
/07: J2.7, J4.7, J6.7, X0.7
/08: J2.8, J4.8, J6.8, X0.8
/09: J2.9, J4.9, J6.9, X0.9
/10: J2.10, J4.10, J6.10, X0.10
/11: J3.1, J5.1, X0.14
/12: J3.2, J5.2, X0.15
/13: J3.3, J5.3, X0.16
/14: J3.4, J5.4, X0.17
/15: J3.5, J5.5, X0.18
/16: J3.6, J5.6, X0.19
/17: J3.7, J5.7, X0.20
/18: J3.8, J5.8, X0.21
/19: J3.9, J5.9, X0.22
/20: J3.10, J5.10, X0.23
/A: R1.2, X0.12
/D2_SDA: J1.4, U1.5 (SDA), X0.25
/D3_SCL: J1.3, U1.6 (SCL), X0.24
GND: J1.1, U1.2 (A1), U1.3 (A2), U1.4 (GND), X0.26
unnamed: R1.1, U1.1 (A0)

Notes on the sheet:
Signal A: HIGH = Card 1 LOW = Card 2
Optional EEPROM to identify card and bay.

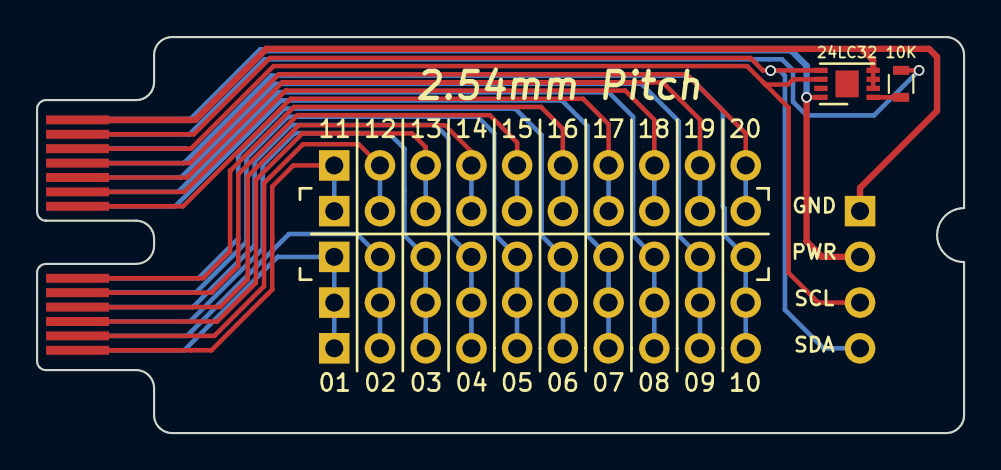
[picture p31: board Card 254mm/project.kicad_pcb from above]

Board: 2 copper layers, 51.5 x 22.0 mm, 9 parts (0 on the bottom side), 26 nets.

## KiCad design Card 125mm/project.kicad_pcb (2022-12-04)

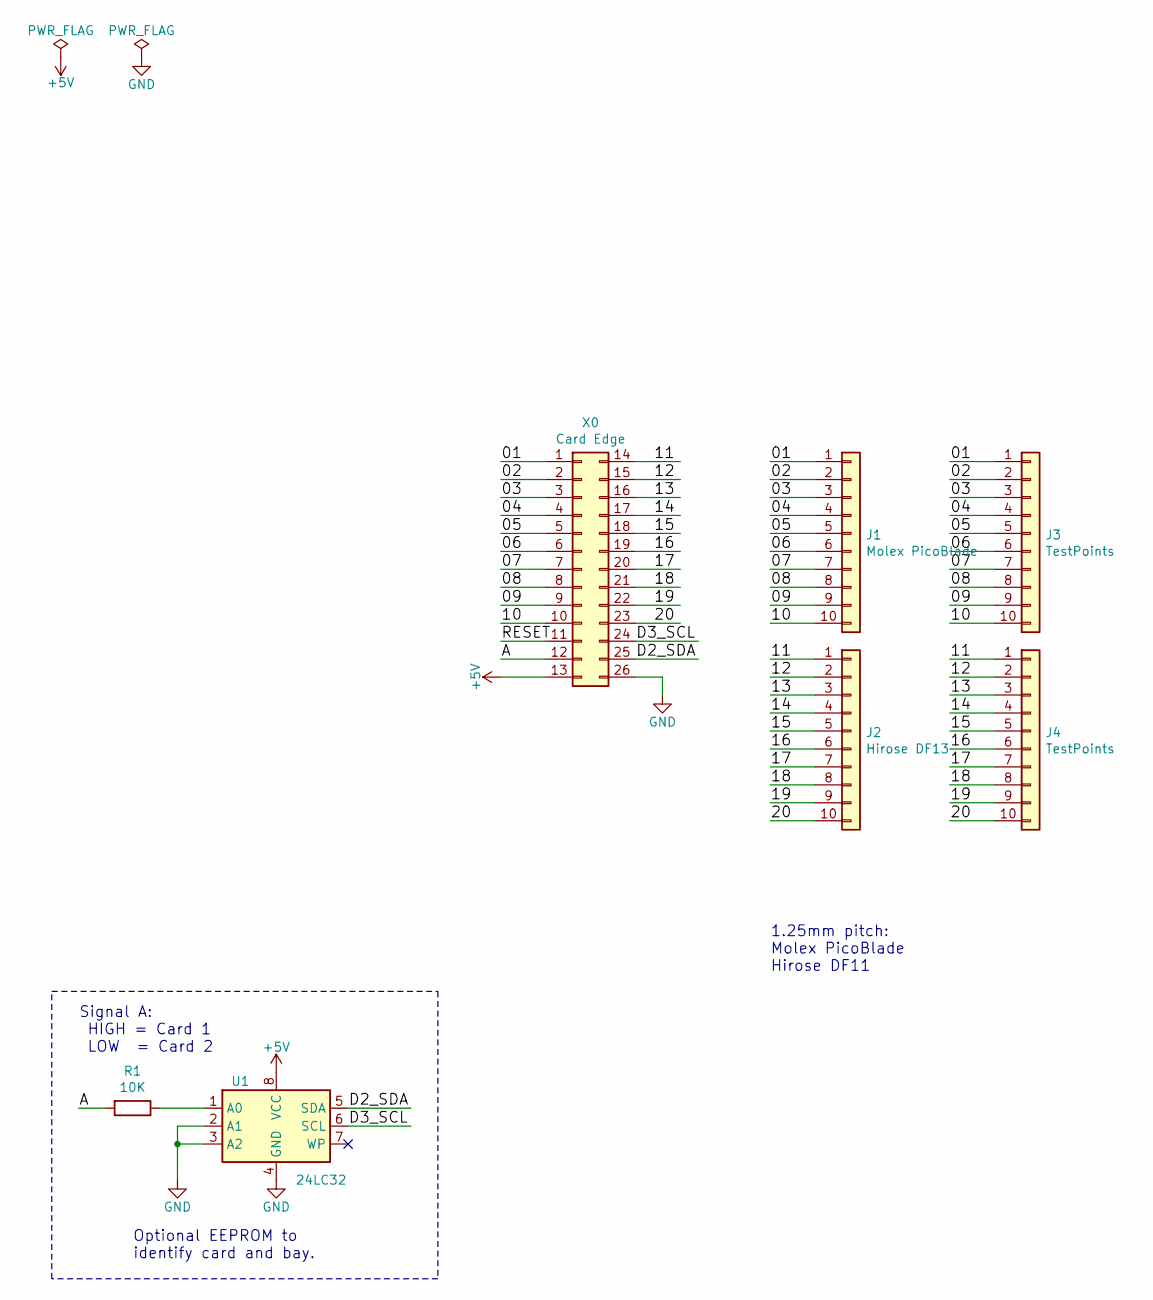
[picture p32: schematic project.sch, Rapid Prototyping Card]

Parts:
J1: Molex PicoBlade; Molex_PicoBlade_53047-1010_1x10_P1.25mm_Vertical
J2: Hirose DF13; Hirose_DF13-10P-1.25DSA_1x10_P1.25mm_Vertical
J3, J4: TestPoints; TestPoints_1x10_P1.25mm_Vertical
R1: 10K; R_0603
U1: 24LC32; DFN-8-1EP_3x2mm
X0: Card Edge; MEC8-113-CARD_2

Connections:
+5V: U1.8 (VCC), X0.13
/01: J1.1, J3.1, X0.1
/02: J1.2, J3.2, X0.2
/03: J1.3, J3.3, X0.3
/04: J1.4, J3.4, X0.4
/05: J1.5, J3.5, X0.5
/06: J1.6, J3.6, X0.6
/07: J1.7, J3.7, X0.7
/08: J1.8, J3.8, X0.8
/09: J1.9, J3.9, X0.9
/10: J1.10, J3.10, X0.10
/11: J2.1, J4.1, X0.14
/12: J2.2, J4.2, X0.15
/13: J2.3, J4.3, X0.16
/14: J2.4, J4.4, X0.17
/15: J2.5, J4.5, X0.18
/16: J2.6, J4.6, X0.19
/17: J2.7, J4.7, X0.20
/18: J2.8, J4.8, X0.21
/19: J2.9, J4.9, X0.22
/20: J2.10, J4.10, X0.23
/A: R1.2, X0.12
/D2_SDA: U1.5 (SDA), X0.25
/D3_SCL: U1.6 (SCL), X0.24
GND: U1.2 (A1), U1.3 (A2), U1.4 (GND), X0.26
unnamed: R1.1, U1.1 (A0)

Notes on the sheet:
Signal A: HIGH = Card 1 LOW = Card 2
Optional EEPROM to identify card and bay.
1.25mm pitch: Molex PicoBlade Hirose DF11

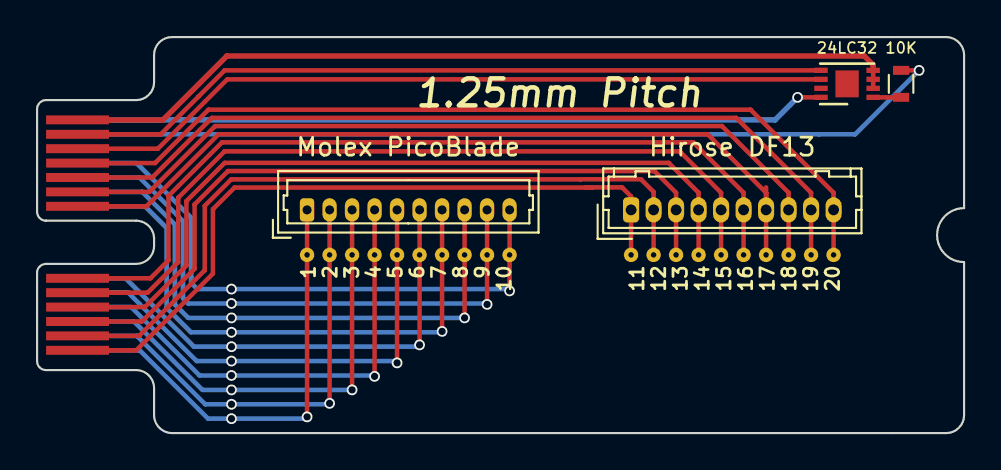
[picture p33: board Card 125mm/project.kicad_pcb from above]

Board: 2 copper layers, 51.5 x 22.0 mm, 7 parts (0 on the bottom side), 26 nets.

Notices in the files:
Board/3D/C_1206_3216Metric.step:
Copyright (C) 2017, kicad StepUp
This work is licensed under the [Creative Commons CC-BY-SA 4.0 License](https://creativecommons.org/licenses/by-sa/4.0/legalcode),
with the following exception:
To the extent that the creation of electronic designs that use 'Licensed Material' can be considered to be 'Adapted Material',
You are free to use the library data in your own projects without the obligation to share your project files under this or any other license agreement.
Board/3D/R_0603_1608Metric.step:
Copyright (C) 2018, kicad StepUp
